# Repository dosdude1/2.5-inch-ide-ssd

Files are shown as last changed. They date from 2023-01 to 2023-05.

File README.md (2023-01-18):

# 2.5-inch IDE SSD

A custom-designed IDE SSD for use in any machine that utilizies a 2.5" IDE hard disk. 

The design is based on the Silicon Motion SM2236 controller, and is compatible with up to four 512Gbit (64GB) BGA152 or BGA132 NANDs.

## Important Info

WARNING: THE SILICON MOTION SM2236 CONTROLLER PINOUT AND IMPLEMENTATION HAVE BEEN REVERSE ENGINEERED FROM OPEN DOCUMENTS AND SALVAGED PCBS, ALL OF WHICH HAVE BEEN LEGALLY OBTAINED. DO NOT EXPECT THIS TO BE CORRECT, CHECK FOR YOURSELF.

### NAND Info

- The NAND ICs used on this PCB must be explicitly supported by the SM2236 controller. All supported NAND ICs are listed in the SM2236 MPTool, or "Mass Production Tool". Be sure to verify compatibility before installing NANDs.

- All installed NAND ICs must match.

- Check the datasheet for your desired NAND ICs to determine their rated I/O voltage, and populate the correct resistor position on the board to set either 3.3V or 1.8V. This is shown in the schematic diagram.

## Programming

Upon the completion of board assembly, the SM2236 controller must be programmed for the NAND ICs you have installed. To do so, you must utilize an IDE to USB adapter to connect the drive to a PC running Windows (using native IDE for this will not work). Then, the SM2236 MPTool must be used to set all the desired drive information, select the part number of NAND ICs you have installed, and program the drive.

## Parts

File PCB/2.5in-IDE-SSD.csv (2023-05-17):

Comment | Designator | Footprint | LCSC
10uF | C1 | Capacitor_SMD:C_0805_2012Metric | C15850
1uF | C12,C13,C41,C42 | Capacitor_SMD:C_0603_1608Metric | C5673
100nF | C2,C4,C6,C8,C10,C11,C14,C15,C16,C17,C18,C19,C20,C21,C22,C23,C24,C29,C30,C31,C32,C33,C34,C35,C36 | Capacitor_SMD:C_0402_1005Metric | C1525
10uF | C25,C26,C27,C28,C37,C38,C39,C40 | Capacitor_SMD:C_0603_1608Metric | C1691
150nF | C3,C5,C7,C9 | Capacitor_SMD:C_0402_1005Metric | C576725
LED | D1 | LED_SMD:LED_0603_1608Metric | C5160703
82 | R1,R5,R6,R8,R9,R10,R11,R12 | Resistor_SMD:R_0402_1005Metric | C163453
330 | R14,R15 | Resistor_SMD:R_0402_1005Metric | C105875
10k | R16,R27,R28 | Resistor_SMD:R_0402_1005Metric | C60490
22 | R2,R3,R7 | Resistor_SMD:R_0402_1005Metric | C114765
2k | R21,R22,R23,R24 | Resistor_SMD:R_0402_1005Metric | C60488
0 | R25 | Resistor_SMD:R_0603_1608Metric | C100044
0 | R26 | Resistor_SMD:R_0402_1005Metric | C60485
33 | RN1,RN2,RN3,RN4 | Resistor_SMD:R_Array_Convex_4x0402 | C136851

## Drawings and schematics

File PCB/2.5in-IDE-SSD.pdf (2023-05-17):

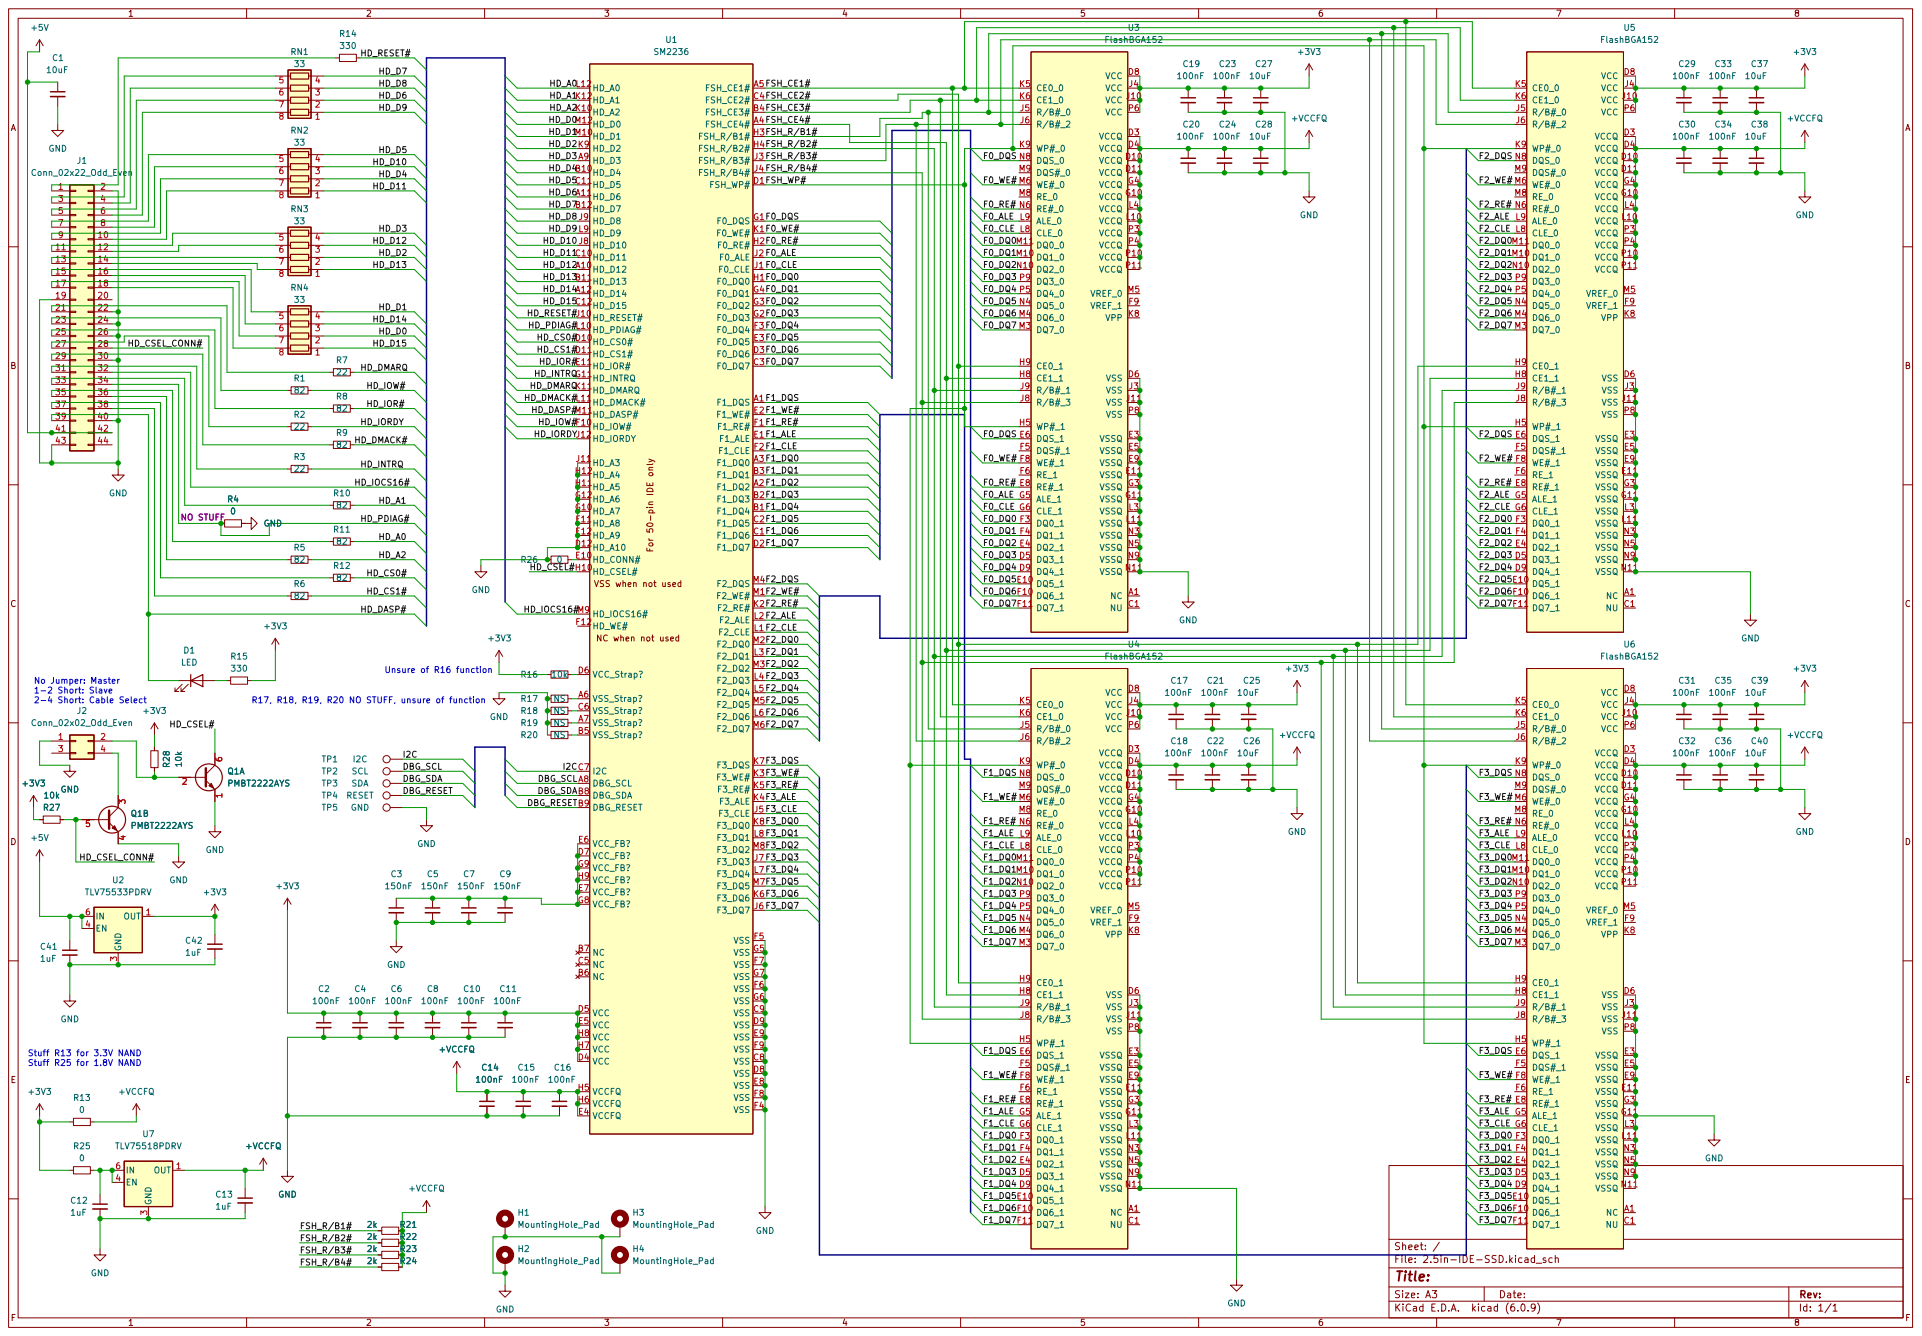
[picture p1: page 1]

Unsure of R16 function R17, R18, R19, R20 NO STUFF, unsure of function GND
2-4 Short: Cable Select Stuff R13 for 3.3V NAND

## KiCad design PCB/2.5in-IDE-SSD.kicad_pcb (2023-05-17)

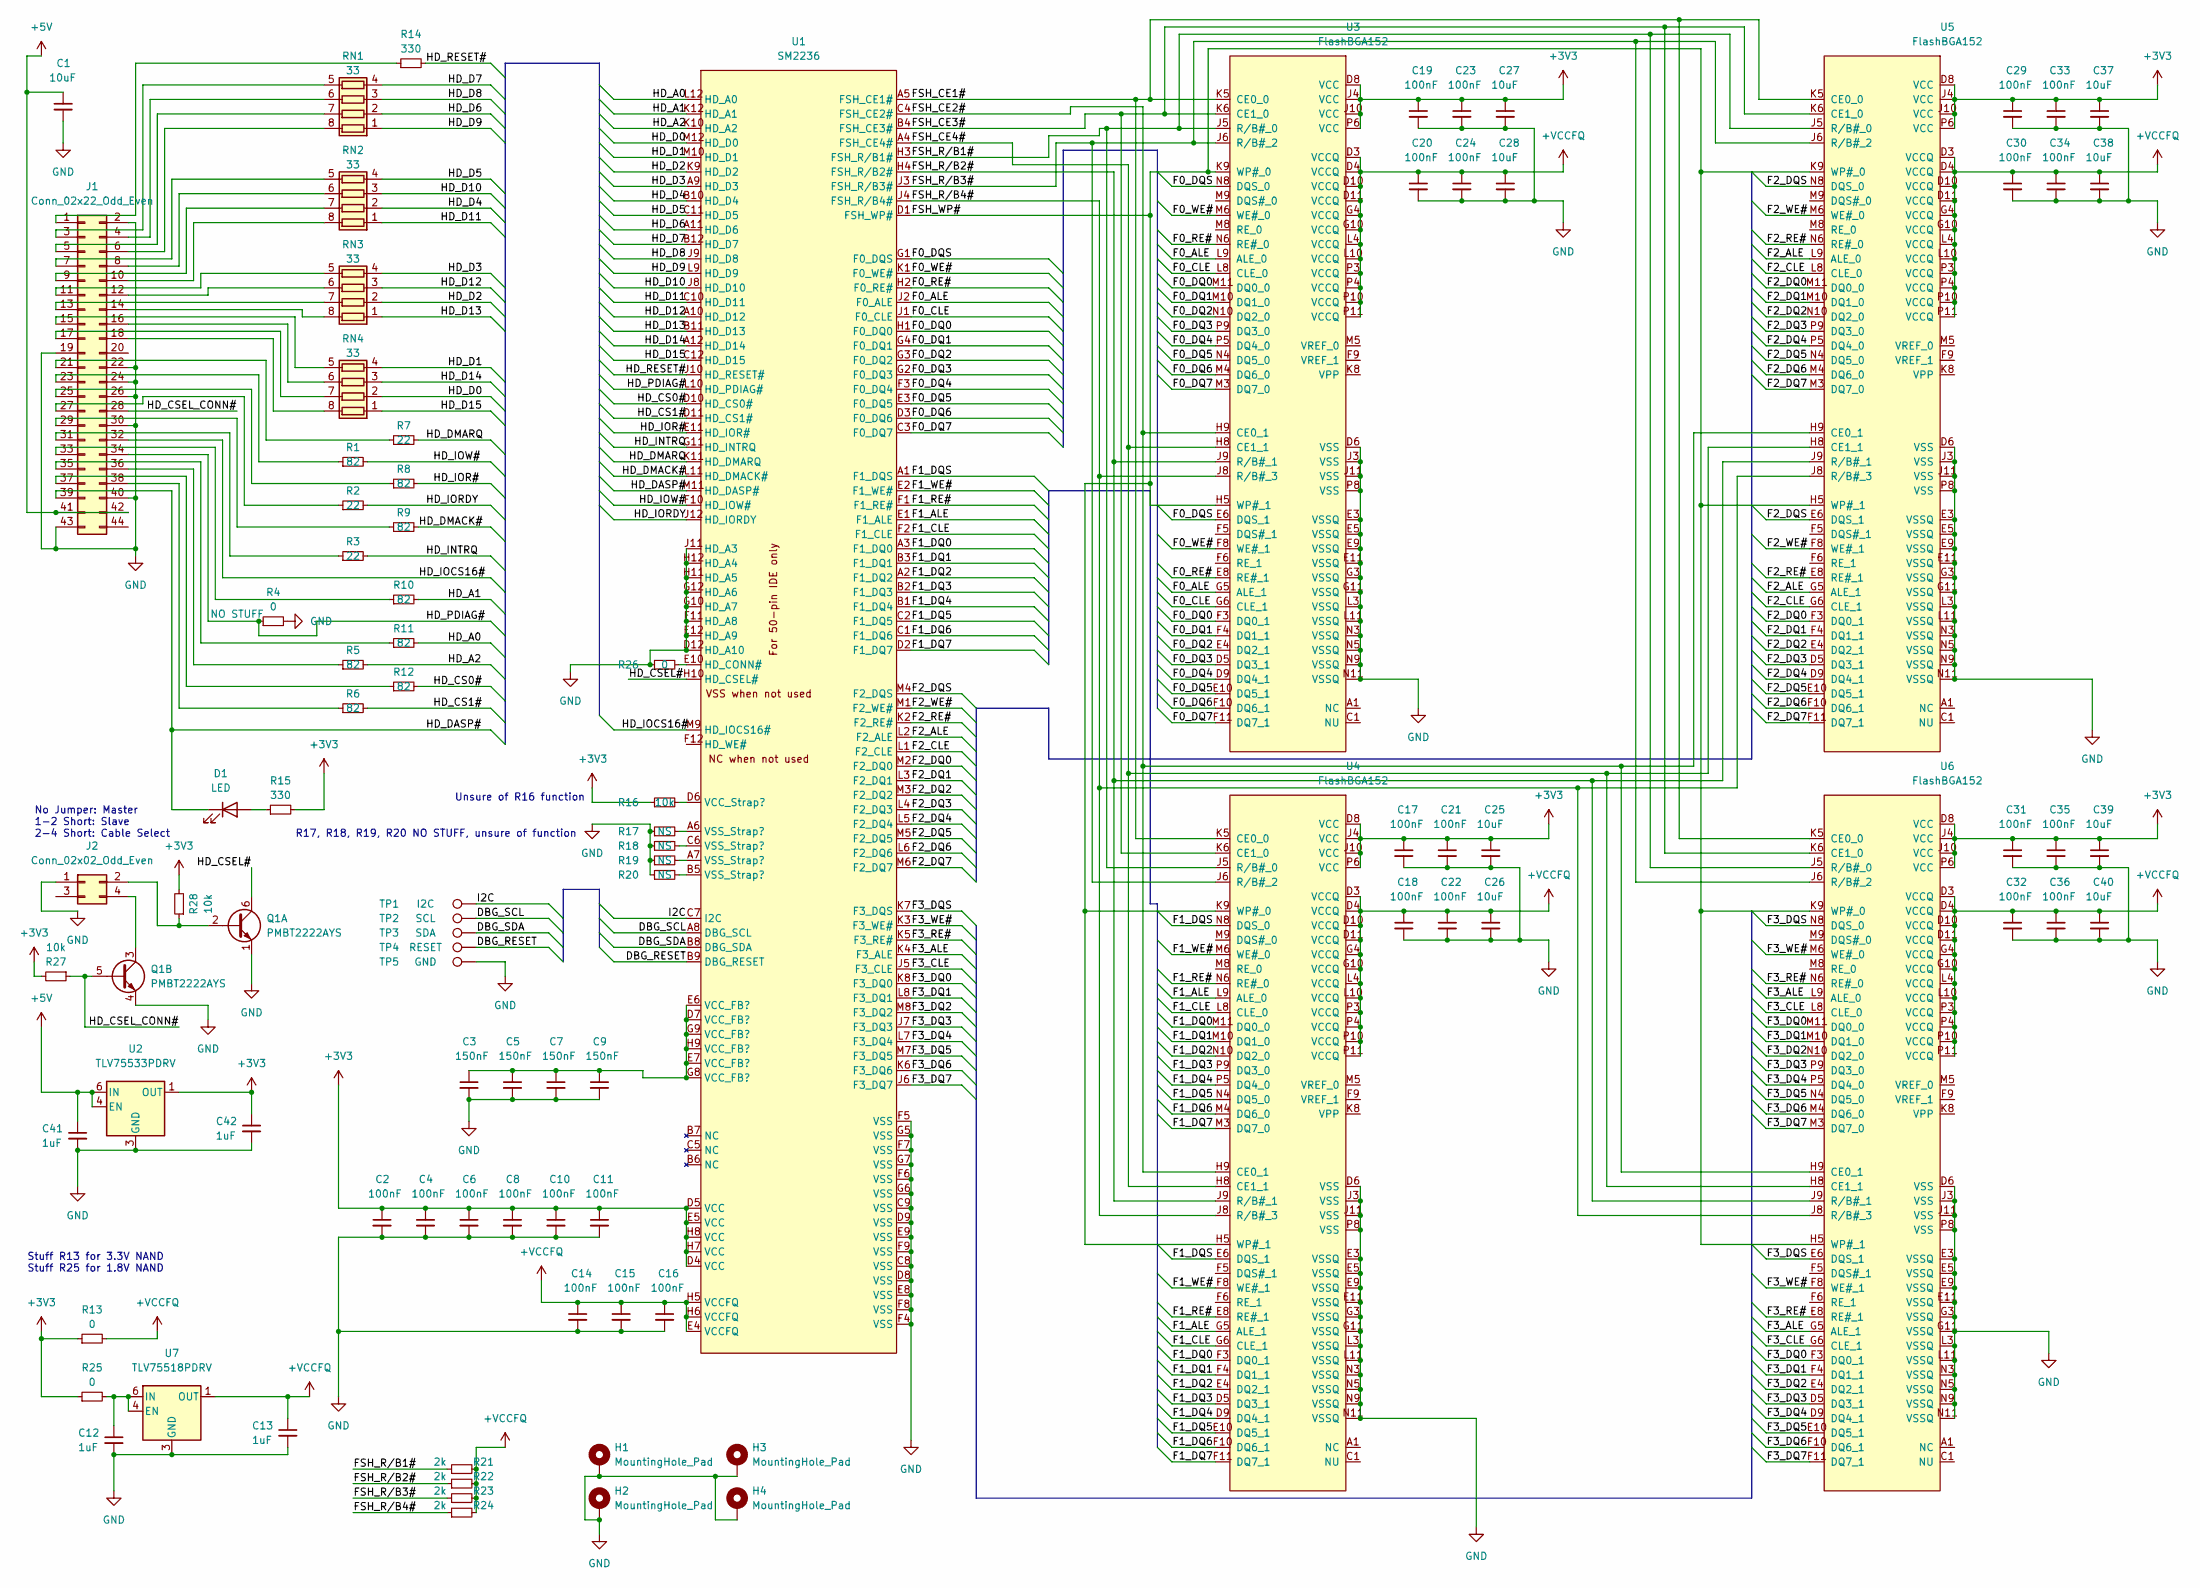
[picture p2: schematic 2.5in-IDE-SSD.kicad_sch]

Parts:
C1: 10uF; C_0805_2012Metric; LCSC C15850
C2, C4, C6, C8, C10, C11, C14, C15, C16, C17, C18, C19, C20, C21, C22, C23, C24, C29, C30, C31, C32, C33, C34, C35, C36: 100nF; C_0402_1005Metric; LCSC C1525
C3, C5, C7, C9: 150nF; C_0402_1005Metric; LCSC C576725
C12, C13, C41, C42: 1uF; C_0603_1608Metric; LCSC C5673
C25, C26, C27, C28, C37, C38, C39, C40: 10uF; C_0603_1608Metric; LCSC C1691
D1: LED; LED_0603_1608Metric; LCSC C5160703
H1, H2, H3, H4: MountingHole_Pad; MountingHole_2.2mm_M2_ISO7380_Pad_TopBottom
J1: Conn_02x22_Odd_Even; 2x22_2mm_border_conn
J2: Conn_02x02_Odd_Even; 2x2_2mm_border_conn
Q1: PMBT2222AYS; SOT-363_SC-70-6
R1, R5, R6, R8, R9, R10, R11, R12: 82; R_0402_1005Metric; LCSC C163453
R2, R3, R7: 22; R_0402_1005Metric; LCSC C114765
R4, R26: 0; R_0402_1005Metric; LCSC C60485
R13, R25: 0; R_0603_1608Metric; LCSC C100044
R14, R15: 330; R_0402_1005Metric; LCSC C105875
R16, R27, R28: 10k; R_0402_1005Metric; LCSC C60490
R17, R18, R19, R20: NS; R_0402_1005Metric
R21, R22, R23, R24: 2k; R_0402_1005Metric; LCSC C60488
RN1, RN2, RN3, RN4: 33; R_Array_Convex_4x0402; LCSC C136851
TP1: I2C; TestPoint_Pad_1.0x1.0mm
TP2: SCL; TestPoint_Pad_1.0x1.0mm
TP3: SDA; TestPoint_Pad_1.0x1.0mm
TP4: RESET; TestPoint_Pad_1.0x1.0mm
TP5: GND; TestPoint_Pad_1.0x1.0mm
U1: SM2236; BGA-144_12x12_9.0x9.0mm
U2: TLV75533PDRV; WSON-6-1EP_2x2mm_P0.65mm_EP1x1.6mm
U3, U4, U5, U6: FlashBGA152; BGA-152_14x18mm_Layout13x17_P0.5mm
U7: TLV75518PDRV; WSON-6-1EP_2x2mm_P0.65mm_EP1x1.6mm

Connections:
+3V3: C2.1, C4.1, C6.1, C8.1, C10.1, C11.1, C17.1, C19.1, C21.1, C23.1, C25.1, C27.1, C29.1, C31.1, C33.1, C35.1, C37.1, C39.1, C42.1, R13.1, R15.2, R16.1, R25.1, R27.2, R28.2, U1.D4 (VCC), U1.D5 (VCC), U1.E5 (VCC), U1.H7 (VCC), U1.H8 (VCC), U2.1 (OUT), U3.D8 (VCC), U3.J4 (VCC), U3.J10 (VCC), U3.P6 (VCC), U4.D8 (VCC), U4.J4 (VCC), U4.J10 (VCC), U4.P6 (VCC), U5.D8 (VCC), U5.J4 (VCC), U5.J10 (VCC), U5.P6 (VCC), U6.D8 (VCC), U6.J4 (VCC), U6.J10 (VCC), U6.P6 (VCC)
+5V: C1.1, C41.1, J1.41, J1.42, U2.4 (EN), U2.6 (IN)
+VCCFQ: C13.1, C14.1, C15.1, C16.1, C18.1, C20.1, C22.1, C24.1, C26.1, C28.1, C30.1, C32.1, C34.1, C36.1, C38.1, C40.1, R13.2, R21.2, R22.2, R23.2, R24.2, U1.E4 (VCCFQ), U1.H5 (VCCFQ), U1.H6 (VCCFQ), U3.D3 (VCCQ), U3.D4 (VCCQ), U3.D10 (VCCQ), U3.D11 (VCCQ), U3.G4 (VCCQ), U3.G10 (VCCQ), U3.L4 (VCCQ), U3.L10 (VCCQ), U3.P3 (VCCQ), U3.P4 (VCCQ), U3.P10 (VCCQ), U3.P11 (VCCQ), U4.D3 (VCCQ), U4.D4 (VCCQ), U4.D10 (VCCQ), U4.D11 (VCCQ), U4.G4 (VCCQ), U4.G10 (VCCQ), U4.L4 (VCCQ), U4.L10 (VCCQ), U4.P3 (VCCQ), U4.P4 (VCCQ), U4.P10 (VCCQ), U4.P11 (VCCQ), U5.D3 (VCCQ), U5.D4 (VCCQ), U5.D10 (VCCQ), U5.D11 (VCCQ), U5.G4 (VCCQ), U5.G10 (VCCQ), U5.L4 (VCCQ), U5.L10 (VCCQ), U5.P3 (VCCQ), U5.P4 (VCCQ), U5.P10 (VCCQ), U5.P11 (VCCQ), U6.D3 (VCCQ), U6.D4 (VCCQ), U6.D10 (VCCQ), U6.D11 (VCCQ), U6.G4 (VCCQ), U6.G10 (VCCQ), U6.L4 (VCCQ), U6.L10 (VCCQ), U6.P3 (VCCQ), U6.P4 (VCCQ), U6.P10 (VCCQ), U6.P11 (VCCQ), U7.1 (OUT)
/DBG_RESET: TP4.1, U1.B9 (DBG_RESET); also elsewhere on the board
/DBG_SCL: TP2.1, U1.A8 (DBG_SCL); also elsewhere on the board
/DBG_SDA: TP3.1, U1.B8 (DBG_SDA); also elsewhere on the board
/F0_ALE: U1.J2 (F0_ALE), U3.G5 (ALE_1), U3.L9 (ALE_0)
/F0_CLE: U1.J1 (F0_CLE), U3.G6 (CLE_1), U3.L8 (CLE_0)
/F0_DQ0: U1.H1 (F0_DQ0), U3.F3 (DQ0_1), U3.M11 (DQ0_0)
/F0_DQ1: U1.G4 (F0_DQ1), U3.F4 (DQ1_1), U3.M10 (DQ1_0)
/F0_DQ2: U1.G3 (F0_DQ2), U3.E4 (DQ2_1), U3.N10 (DQ2_0)
/F0_DQ3: U1.G2 (F0_DQ3), U3.D5 (DQ3_1), U3.P9 (DQ3_0)
/F0_DQ4: U1.F3 (F0_DQ4), U3.D9 (DQ4_1), U3.P5 (DQ4_0)
/F0_DQ5: U1.E3 (F0_DQ5), U3.E10 (DQ5_1), U3.N4 (DQ5_0)
/F0_DQ6: U1.D3 (F0_DQ6), U3.F10 (DQ6_1), U3.M4 (DQ6_0)
/F0_DQ7: U1.C3 (F0_DQ7), U3.F11 (DQ7_1), U3.M3 (DQ7_0)
/F0_DQS: U1.G1 (F0_DQS), U3.E6 (DQS_1), U3.N8 (DQS_0)
/F0_RE#: U1.H2 (F0_RE#), U3.E8 (RE#_1), U3.N6 (RE#_0)
/F0_WE#: U1.K1 (F0_WE#), U3.F8 (WE#_1), U3.M6 (WE#_0)
/F1_ALE: U1.E1 (F1_ALE), U4.G5 (ALE_1), U4.L9 (ALE_0)
/F1_CLE: U1.F2 (F1_CLE), U4.G6 (CLE_1), U4.L8 (CLE_0)
/F1_DQ0: U1.A3 (F1_DQ0), U4.F3 (DQ0_1), U4.M11 (DQ0_0)
/F1_DQ1: U1.B3 (F1_DQ1), U4.F4 (DQ1_1), U4.M10 (DQ1_0)
/F1_DQ2: U1.A2 (F1_DQ2), U4.E4 (DQ2_1), U4.N10 (DQ2_0)
/F1_DQ3: U1.B2 (F1_DQ3), U4.D5 (DQ3_1), U4.P9 (DQ3_0)
/F1_DQ4: U1.B1 (F1_DQ4), U4.D9 (DQ4_1), U4.P5 (DQ4_0)
/F1_DQ5: U1.C2 (F1_DQ5), U4.E10 (DQ5_1), U4.N4 (DQ5_0)
/F1_DQ6: U1.C1 (F1_DQ6), U4.F10 (DQ6_1), U4.M4 (DQ6_0)
/F1_DQ7: U1.D2 (F1_DQ7), U4.F11 (DQ7_1), U4.M3 (DQ7_0)
/F1_DQS: U1.A1 (F1_DQS), U4.E6 (DQS_1), U4.N8 (DQS_0)
/F1_RE#: U1.F1 (F1_RE#), U4.E8 (RE#_1), U4.N6 (RE#_0)
/F1_WE#: U1.E2 (F1_WE#), U4.F8 (WE#_1), U4.M6 (WE#_0)
/F2_ALE: U1.L2 (F2_ALE), U5.G5 (ALE_1), U5.L9 (ALE_0)
/F2_CLE: U1.L1 (F2_CLE), U5.G6 (CLE_1), U5.L8 (CLE_0)
/F2_DQ0: U1.M2 (F2_DQ0), U5.F3 (DQ0_1), U5.M11 (DQ0_0)
/F2_DQ1: U1.L3 (F2_DQ1), U5.F4 (DQ1_1), U5.M10 (DQ1_0)
/F2_DQ2: U1.M3 (F2_DQ2), U5.E4 (DQ2_1), U5.N10 (DQ2_0)
/F2_DQ3: U1.L4 (F2_DQ3), U5.D5 (DQ3_1), U5.P9 (DQ3_0)
/F2_DQ4: U1.L5 (F2_DQ4), U5.D9 (DQ4_1), U5.P5 (DQ4_0)
/F2_DQ5: U1.M5 (F2_DQ5), U5.E10 (DQ5_1), U5.N4 (DQ5_0)
/F2_DQ6: U1.L6 (F2_DQ6), U5.F10 (DQ6_1), U5.M4 (DQ6_0)
/F2_DQ7: U1.M6 (F2_DQ7), U5.F11 (DQ7_1), U5.M3 (DQ7_0)
/F2_DQS: U1.M4 (F2_DQS), U5.E6 (DQS_1), U5.N8 (DQS_0)
/F2_RE#: U1.K2 (F2_RE#), U5.E8 (RE#_1), U5.N6 (RE#_0)
/F2_WE#: U1.M1 (F2_WE#), U5.F8 (WE#_1), U5.M6 (WE#_0)
/F3_ALE: U1.K4 (F3_ALE), U6.G5 (ALE_1), U6.L9 (ALE_0)
/F3_CLE: U1.J5 (F3_CLE), U6.G6 (CLE_1), U6.L8 (CLE_0)
/F3_DQ0: U1.K8 (F3_DQ0), U6.F3 (DQ0_1), U6.M11 (DQ0_0)
/F3_DQ1: U1.L8 (F3_DQ1), U6.F4 (DQ1_1), U6.M10 (DQ1_0)
/F3_DQ2: U1.M8 (F3_DQ2), U6.E4 (DQ2_1), U6.N10 (DQ2_0)
/F3_DQ3: U1.J7 (F3_DQ3), U6.D5 (DQ3_1), U6.P9 (DQ3_0)
/F3_DQ4: U1.L7 (F3_DQ4), U6.D9 (DQ4_1), U6.P5 (DQ4_0)
/F3_DQ5: U1.M7 (F3_DQ5), U6.E10 (DQ5_1), U6.N4 (DQ5_0)
/F3_DQ6: U1.K6 (F3_DQ6), U6.F10 (DQ6_1), U6.M4 (DQ6_0)
/F3_DQ7: U1.J6 (F3_DQ7), U6.F11 (DQ7_1), U6.M3 (DQ7_0)
/F3_DQS: U1.K7 (F3_DQS), U6.E6 (DQS_1), U6.N8 (DQS_0)
/F3_RE#: U1.K5 (F3_RE#), U6.E8 (RE#_1), U6.N6 (RE#_0)
/F3_WE#: U1.K3 (F3_WE#), U6.F8 (WE#_1), U6.M6 (WE#_0)
/FSH_CE1#: U1.A5 (FSH_CE1#), U3.K5 (CE0_0), U4.K5 (CE0_0), U5.K5 (CE0_0), U6.K5 (CE0_0)
/FSH_CE2#: U1.C4 (FSH_CE2#), U3.H9 (CE0_1), U4.H9 (CE0_1), U5.H9 (CE0_1), U6.H9 (CE0_1)
/FSH_CE3#: U1.B4 (FSH_CE3#), U3.K6 (CE1_0), U4.K6 (CE1_0), U5.K6 (CE1_0), U6.K6 (CE1_0)
/FSH_CE4#: U1.A4 (FSH_CE4#), U3.H8 (CE1_1), U4.H8 (CE1_1), U5.H8 (CE1_1), U6.H8 (CE1_1)
/FSH_R/B1#: R21.1, U1.H3 (FSH_R/B1#), U3.J5 (R/B#_0), U4.J5 (R/B#_0), U5.J5 (R/B#_0), U6.J5 (R/B#_0)
/FSH_R/B2#: R22.1, U1.H4 (FSH_R/B2#), U3.J9 (R/B#_1), U4.J9 (R/B#_1), U5.J9 (R/B#_1), U6.J9 (R/B#_1)
/FSH_R/B3#: R23.1, U1.J3 (FSH_R/B3#), U3.J6 (R/B#_2), U4.J6 (R/B#_2), U5.J6 (R/B#_2), U6.J6 (R/B#_2)
/FSH_R/B4#: R24.1, U1.J4 (FSH_R/B4#), U3.J8 (R/B#_3), U4.J8 (R/B#_3), U5.J8 (R/B#_3), U6.J8 (R/B#_3)
/FSH_WP#: U1.D1 (FSH_WP#), U3.H5 (WP#_1), U3.K9 (WP#_0), U4.H5 (WP#_1), U4.K9 (WP#_0), U5.H5 (WP#_1), U5.K9 (WP#_0), U6.H5 (WP#_1), U6.K9 (WP#_0)
/HD_A0: R11.2, U1.L12 (HD_A0)
/HD_A1: R10.2, U1.K12 (HD_A1)
/HD_A2: R5.2, U1.K10 (HD_A2)
/HD_CS0#: R12.2, U1.D10 (HD_CS0#)
/HD_CS1#: R6.2, U1.D11 (HD_CS1#)
/HD_CSEL#: Q1.6 (C1), U1.H10 (HD_CSEL#)
/HD_CSEL_CONN#: J1.28, Q1.5 (B2), R27.1
/HD_D0: RN4.2 (R2.1), U1.M12 (HD_D0)
/HD_D1: RN4.4 (R4.1), U1.M10 (HD_D1)
/HD_D2: RN3.2 (R2.1), U1.K9 (HD_D2)
/HD_D3: RN3.4 (R4.1), U1.A9 (HD_D3)
/HD_D4: RN2.2 (R2.1), U1.B10 (HD_D4)
/HD_D5: RN2.4 (R4.1), U1.C11 (HD_D5)
/HD_D6: RN1.2 (R2.1), U1.A11 (HD_D6)
/HD_D7: RN1.4 (R4.1), U1.B12 (HD_D7)
/HD_D8: RN1.3 (R3.1), U1.J9 (HD_D8)
/HD_D9: RN1.1 (R1.1), U1.L9 (HD_D9)
/HD_D10: RN2.3 (R3.1), U1.J8 (HD_D10)
/HD_D11: RN2.1 (R1.1), U1.C10 (HD_D11)
/HD_D12: RN3.3 (R3.1), U1.A10 (HD_D12)
/HD_D13: RN3.1 (R1.1), U1.B11 (HD_D13)
/HD_D14: RN4.3 (R3.1), U1.A12 (HD_D14)
/HD_D15: RN4.1 (R1.1), U1.C12 (HD_D15)
/HD_DASP#: D1.1 (K), J1.39, U1.M11 (HD_DASP#)
/HD_DMACK#: R9.2, U1.L11 (HD_DMACK#)
/HD_DMARQ: R7.2, U1.K11 (HD_DMARQ)
/HD_INTRQ: R3.2, U1.G11 (HD_INTRQ)
/HD_IOCS16#: J1.32, U1.M9 (HD_IOCS16#)
/HD_IOR#: R8.2, U1.E11 (HD_IOR#)
/HD_IORDY: R2.2, U1.J12 (HD_IORDY)
/HD_IOW#: R1.2, U1.F10 (HD_IOW#)
/HD_PDIAG#: J1.34, R4.1, U1.L10 (HD_PDIAG#)
/HD_RESET#: R14.2, U1.J10 (HD_RESET#)
/I2C: TP1.1, U1.C7 (I2C); also elsewhere on the board
GND: C1.2, C2.2, C3.2, C4.2, C5.2, C6.2, C7.2, C8.2, C9.2, C10.2, C11.2, C12.2, C13.2, C14.2, C15.2, C16.2, C17.2, C18.2, C19.2, C20.2, C21.2, C22.2, C23.2, C24.2, C25.2, C26.2, C27.2, C28.2, C29.2, C30.2, C31.2, C32.2, C33.2, C34.2, C35.2, C36.2, C37.2, C38.2, C39.2, C40.2, C41.2, C42.2, H1.1, H2.1, H3.1, H4.1, J1.2, J1.19, J1.22, J1.24, J1.26, J1.30, J1.40, J1.43, J2.1, Q1.1 (E1), Q1.4 (E2), R4.2, R17.1, R18.1, R19.1, R20.1, R26.1, TP5.1, U1.C8 (VSS), U1.C9 (VSS), U1.D8 (VSS), U1.D9 (VSS), U1.D12 (HD_A10), U1.E8 (VSS), U1.E9 (VSS), U1.E12 (HD_A9), U1.F4 (VSS), U1.F5 (VSS), U1.F6 (VSS), U1.F7 (VSS), U1.F8 (VSS), U1.F9 (VSS), U1.F11 (HD_A8), U1.G5 (VSS), U1.G6 (VSS), U1.G7 (VSS), U1.G10 (HD_A7), U1.G12 (HD_A6), U1.H11 (HD_A5), U1.H12 (HD_A4), U1.J11 (HD_A3), U2.3 (GND), U2.7 (GND), U3.D6 (VSS), U3.E3 (VSSQ), U3.E5 (VSSQ), U3.E9 (VSSQ), U3.E11 (VSSQ), U3.G3 (VSSQ), U3.G11 (VSSQ), U3.J3 (VSS), U3.J11 (VSS), U3.L3 (VSSQ), U3.L11 (VSSQ), U3.N3 (VSSQ), U3.N5 (VSSQ), U3.N9 (VSSQ), U3.N11 (VSSQ), U3.P8 (VSS), U4.D6 (VSS), U4.E3 (VSSQ), U4.E5 (VSSQ), U4.E9 (VSSQ), U4.E11 (VSSQ), U4.G3 (VSSQ), U4.G11 (VSSQ), U4.J3 (VSS), U4.J11 (VSS), U4.L3 (VSSQ), U4.L11 (VSSQ), U4.N3 (VSSQ), U4.N5 (VSSQ), U4.N9 (VSSQ), U4.N11 (VSSQ), U4.P8 (VSS), U5.D6 (VSS), U5.E3 (VSSQ), U5.E5 (VSSQ), U5.E9 (VSSQ), U5.E11 (VSSQ), U5.G3 (VSSQ), U5.G11 (VSSQ), U5.J3 (VSS), U5.J11 (VSS), U5.L3 (VSSQ), U5.L11 (VSSQ), U5.N3 (VSSQ), U5.N5 (VSSQ), U5.N9 (VSSQ), U5.N11 (VSSQ), U5.P8 (VSS), U6.D6 (VSS), U6.E3 (VSSQ), U6.E5 (VSSQ), U6.E9 (VSSQ), U6.E11 (VSSQ), U6.G3 (VSSQ), U6.G11 (VSSQ), U6.J3 (VSS), U6.J11 (VSS), U6.L3 (VSSQ), U6.L11 (VSSQ), U6.N3 (VSSQ), U6.N5 (VSSQ), U6.N9 (VSSQ), U6.N11 (VSSQ), U6.P8 (VSS), U7.3 (GND), U7.7 (GND); also elsewhere on the board
unnamed: C3.1, C5.1, C7.1, C9.1, U1.D7 (VCC_FB?), U1.E6 (VCC_FB?), U1.E7 (VCC_FB?), U1.G8 (VCC_FB?), U1.G9 (VCC_FB?), U1.H9 (VCC_FB?)
unnamed: C12.1, R25.2, U7.4 (EN), U7.6 (IN)
unnamed: D1.2 (A), R15.1
unnamed: J1.1, R14.1
unnamed: J1.3, RN1.5 (R4.2)
unnamed: J1.4, RN1.6 (R3.2)
unnamed: J1.5, RN1.7 (R2.2)
unnamed: J1.6, RN1.8 (R1.2)
unnamed: J1.7, RN2.5 (R4.2)
unnamed: J1.8, RN2.6 (R3.2)
unnamed: J1.9, RN2.7 (R2.2)
unnamed: J1.10, RN2.8 (R1.2)
unnamed: J1.11, RN3.5 (R4.2)
unnamed: J1.12, RN3.6 (R3.2)
unnamed: J1.13, RN3.7 (R2.2)
unnamed: J1.14, RN3.8 (R1.2)
unnamed: J1.15, RN4.5 (R4.2)
unnamed: J1.16, RN4.6 (R3.2)
unnamed: J1.17, RN4.7 (R2.2)
unnamed: J1.18, RN4.8 (R1.2)
unnamed: J1.21, R7.1
unnamed: J1.23, R1.1
unnamed: J1.25, R8.1
unnamed: J1.27, R2.1
unnamed: J1.29, R9.1
unnamed: J1.31, R3.1
unnamed: J1.33, R10.1
unnamed: J1.35, R11.1
unnamed: J1.36, R5.1
unnamed: J1.37, R12.1
unnamed: J1.38, R6.1
unnamed: J2.2, Q1.2 (B1), R28.1
unnamed: J2.4, Q1.3 (C2)
unnamed: R16.2, U1.D6 (VCC_Strap?)
unnamed: R17.2, U1.A6 (VSS_Strap?)
unnamed: R18.2, U1.C6 (VSS_Strap?)
unnamed: R19.2, U1.A7 (VSS_Strap?)
unnamed: R20.2, U1.B5 (VSS_Strap?)
unnamed: R26.2, U1.E10 (HD_CONN#)

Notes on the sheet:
No Jumper: Master 1-2 Short: Slave 2-4 Short: Cable Select
Stuff R13 for 3.3V NAND Stuff R25 for 1.8V NAND
Unsure of R16 function
R17, R18, R19, R20 NO STUFF, unsure of function

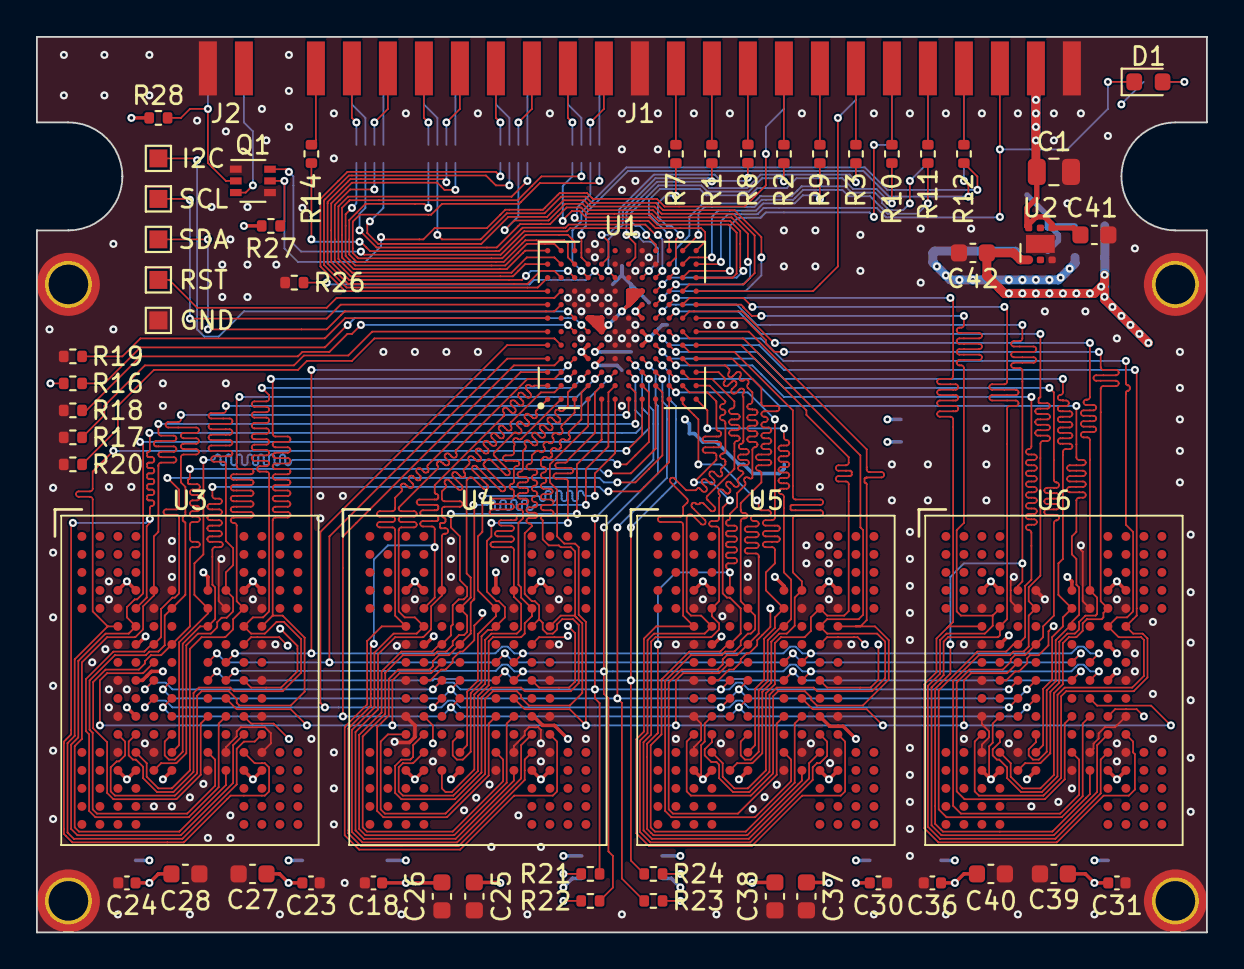
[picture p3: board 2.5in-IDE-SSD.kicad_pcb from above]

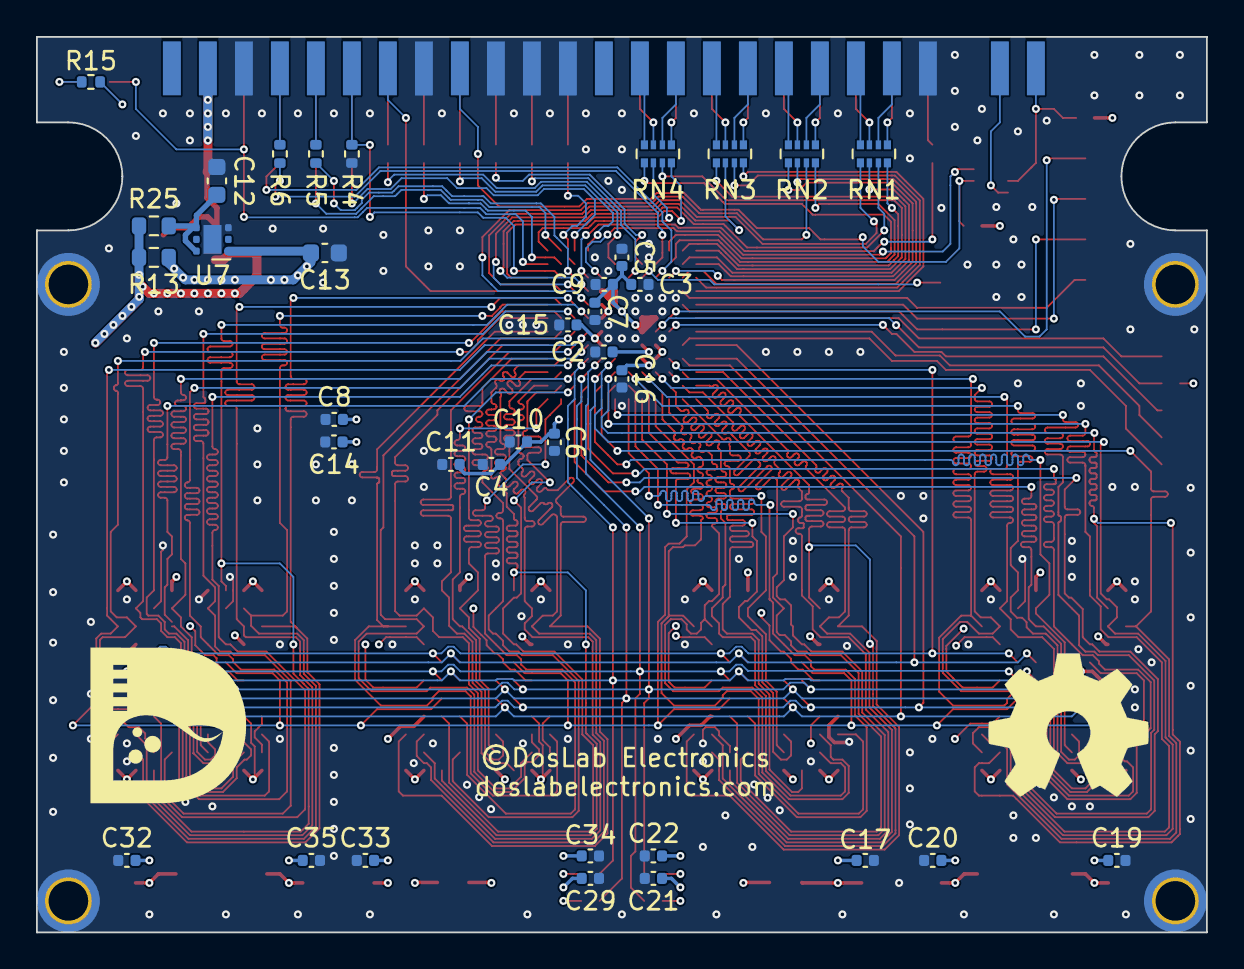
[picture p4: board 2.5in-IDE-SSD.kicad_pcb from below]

Board: 4 copper layers, 65.0 x 49.8 mm, 94 parts (36 on the bottom side), 141 nets.

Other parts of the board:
GND: GND; TestPoint_Pad_1.0x1.0mm
I2C: I2C; TestPoint_Pad_1.0x1.0mm
RST: RESET; TestPoint_Pad_1.0x1.0mm
SCL: SCL; TestPoint_Pad_1.0x1.0mm
SDA: SDA; TestPoint_Pad_1.0x1.0mm

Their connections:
/DBG_RESET: RST.1; also elsewhere on the board
/DBG_SCL: SCL.1; also elsewhere on the board
/DBG_SDA: SDA.1; also elsewhere on the board
/I2C: I2C.1; also elsewhere on the board
GND: GND.1; also elsewhere on the board

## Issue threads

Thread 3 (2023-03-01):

Sun Blade support - does it appear as removable media ?

Sch-LikA, 2023-03-01:
First thanks a lot for that design ! I have a Sun Blade 100 workstation on which I tried numerous IDE to sata / CF / msata ... adapters, but none work, only a (any) regular mechanical hdd does. I think it may be due to the fact that those devices appear as removable media (wild guess for now). Does your ide ssd register as a regular "fixed" hdd ?

dosdude1, 2023-03-04:
Yes, it certainly should. I've had these SSDs work with many machines that are picky about their hard disks.

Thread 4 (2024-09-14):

PCBWay Shared Projects

Jimbo7136, 2024-09-14:
This is more of a request than an issue but I didn't know how else to ask.

Could you upload your project to PCB way shared prjects, please?

I'd like to order it pre-fabricated from there.

Thanks.

Jimbo7136, 2024-09-14:
https://www.pcbway.com/project/

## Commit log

2023-01-18 Added PCB
    [2.5in-IDE-SSD-no-lengthmatch.kicad_pcb, 2.5in-IDE-SSD.kicad_pcb, 2.5in-IDE-SSD.kicad_sch]
2023-05-17 Reversed state of master/slave select, making master mode enabled when jumper is removed
    [2.5in-IDE-SSD.csv, 2.5in-IDE-SSD.kicad_pcb, 2.5in-IDE-SSD.kicad_sch]

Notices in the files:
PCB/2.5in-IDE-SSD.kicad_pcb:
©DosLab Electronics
